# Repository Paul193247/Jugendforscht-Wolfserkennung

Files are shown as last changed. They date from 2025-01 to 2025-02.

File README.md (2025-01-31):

# Jugend forscht: Wolfserkennung

## 1. Idee
Ich war schon immer ein Tierfreund, und als ich wiederholt Artikel im *Stader Tageblatt* gelesen habe, dass Wölfe, die Weidetiere wie Schafe oder Rinder reißen, zum Abschuss freigegeben werden, entstand die Idee zu meinem Projekt. Eine Zusammenarbeit mit der Wolfsberaterin Svenja Oßenbrügge ergab, dass ein KI-unterstütztes Kamerasystem sehr wichtig für das Wolfsmonitoring wäre, da die Hälfte der Wolfsrisse mutmaßlich auf Hunde zurückzuführen sind. Eindeutige Bilder sorgen für Aufklärung, und mein entwickeltes Alarmsystem kann Tiere schützen.

## 2. Ziel
- Das neuronale Netzwerk aus dem Vorjahr verbessern und so anpassen, dass es sowohl Hunde als auch Wölfe erkennen kann.
- Das neuronale Netzwerk mit dem Raspberry Pi verbinden.
- Die Kamera aus dem Vorjahr verbessern.
- Eine Möglichkeit einbauen, dass der Raspberry Pi unabhängig von WLAN-Netzwerken eine SMS senden kann.
- Alles in einer funktionalen Kamerabox verbinden, die bei einer Bewegung ein Video aufnimmt, dieses klassifiziert und gegebenenfalls eine SMS-Nachricht an den Verantwortlichen sendet.

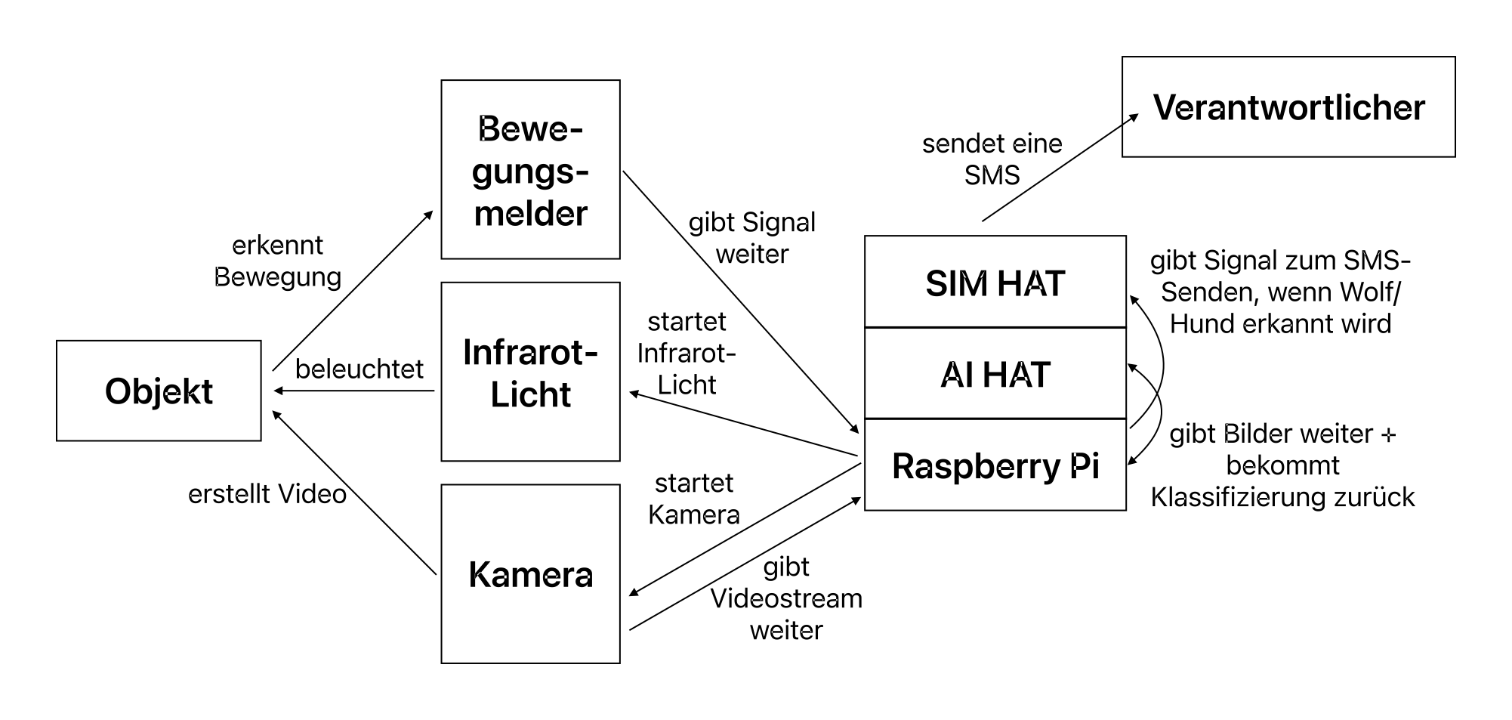
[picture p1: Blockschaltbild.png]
Blockschaltbild


## 3. Vorgehensweise
### 3.1 Wie bin ich vorgegangen?
- Trainingsdaten mit Roboflow vorbereitet.
- Mit YOLOv8 ein Modell erstellt.
- Modell auf Google Colab trainiert.
- Modell in das `.hef`-Format konvertiert.
- Python-Programm geschrieben, das auf dem Raspberry Pi läuft und bei einer Bewegung den Kamera-Stream mit der Klassifizierung öffnet.

### 3.2 Problemlösemethoden bei der KI-Entwicklung
Problem aufgetreten → Hypothese aufstellen → Versuch entwickeln → erneut testen → ggf. einsatzbereit machen oder weitere Lösungen entwickeln.

### 3.3 Verwendete Hardware
#### 3.3.1 Raspberry Pi
Der Raspberry Pi ist ein Minicomputer. Auf diesem läuft das Python-Programm, welches sozusagen alles koordiniert.

#### 3.3.2 Raspberry Pi Kamera v3
Ich verwende die Raspberry Pi Kamera v3, die im Gegensatz zu meiner vorherigen Kamera einen Autofokus hat und keinen Infrarotfilter besitzt. Dadurch kann ich einen Infrarot-Scheinwerfer verwenden.

#### 3.3.3 SIM-HAT
Zur SMS-Benachrichtigung setze ich das Waveshare SIM7600E-H 4G HAT ein, womit der Raspberry Pi unabhängig von WLAN-Netzwerken SMS versenden kann.

#### 3.3.4 Infrarot-LED
Um auch nachts Aufnahmen zu ermöglichen, nutze ich eine Infrarot-LED, die für meine Kamera sichtbar ist, aber andere Tiere nicht stört.

#### 3.3.5 AI-HAT
Mein vorheriges System benötigte ca. 20-30 Sekunden zur Bildverarbeitung. Mit dem Raspberry Pi AI HAT (13 TOPS) kann ich einen 30fps-Videostream live verarbeiten. Dadurch wird das System echtzeitfähig, was eine schnellere Alarmierung ermöglicht.

## 4. Tests
### 4.1 Vorversuch mit meiner Katze
Viele Funktionalitäten meines Systems wurden an meiner Katze entwickelt und getestet.

### 4.2 Hund
Da ich keinen eigenen Hund habe, testete ich die KI mit Hunden von Freunden und Bekannten – sowohl mit einem Videostream als auch mit einzelnen Bildern. Die Erkennungsrate war hoch; wenn ein Hund nicht erkannt wurde, lag es meist daran, dass er weit hinten im Bild war.

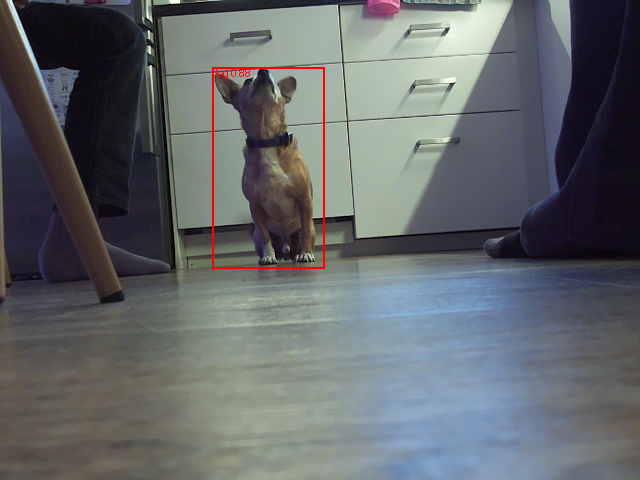
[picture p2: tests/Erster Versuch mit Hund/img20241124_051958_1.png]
Versuch mit Hund

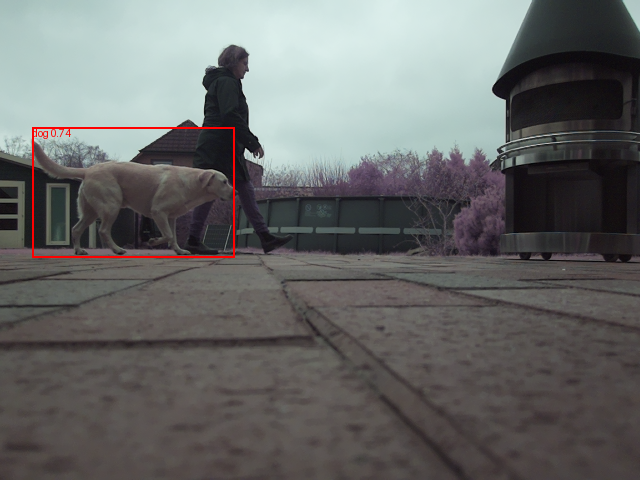
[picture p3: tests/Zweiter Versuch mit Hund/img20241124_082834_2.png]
Versuch mit Hund


### 4.3 Wolf
Um die KI an echten Wölfen zu testen, besuchte ich den Wildpark Schwarze Berge. Dort unterstützte mich die Wolfsberaterin Svenja Oßenbrügge beim Anlocken der Wölfe. Die Genauigkeit meiner KI war sehr zufriedenstellend. Eine Schwäche zeigte sich bei liegenden Wölfen, da es hiervon nur wenige Trainingsbilder gab.

Versuch mit Wolf

## 5. Was ist neu?
- Raspberry Pi
- AI-HAT
- SIM-HAT
- Raspberry Pi Kamera
- Neuronales Netzwerk
- Infrarot-LED
- Python-Programm
- 3D-gedruckte Box

## 6. Zielerreichung
- Ich habe das neuronale Netzwerk mit YOLOv8 verbessert.
- Die KI kann nun Hunde und Wölfe erkennen, was entscheidend für das Wolfsmonitoring ist.
- Meine Kamera hat jetzt Autofokus.
- Der Raspberry Pi kann nun SMS-Nachrichten verschicken.
- Alle Komponenten sind in einer funktionalen Kamerabox integriert.

## 7. Ergebnisdiskussion
Mein Kamerasystem soll Tierhalter wie Schafhirten vor angreifenden Hunden oder Wölfen warnen, damit sie rechtzeitig reagieren und ihre Tiere schützen können. Außerdem soll es Wolfsberatern bei Wildrissen helfen, zwischen Hund und Wolf zu unterscheiden und wichtige Erkenntnisse über das Verhalten von Wölfen liefern. Derzeit fehlen oft Bild- oder Videobeweise bei Wolfsrissen, sodass Entscheidungen nur auf DNA-Proben und Angriffsweisen basieren. Videoaufnahmen könnten Fehleinschätzungen minimieren und das Wolfsmonitoring verbessern. 

Alle Systemkomponenten wurden erfolgreich getestet: Der Bewegungsmelder funktionierte mit meiner Katze, und die KI erkannte zuverlässig Hunde und Wölfe – dies konnte ich mit echten Tieren bestätigen. Mein System ist nun echtzeitfähig, wetterfest, tag- und nachttauglich sowie internetfähig. 

In Zukunft könnte eine Zusammenarbeit mit kompetenten Partnern wie Schäfern, Jägern, Wolfsberatern, Verhaltensforschern, Rangern oder Wildhütern angestrebt werden.

## 8. Danksagung
Ich möchte mich herzlich bei all jenen bedanken, die mich bei meinem Projekt unterstützt und motiviert haben:
- **Privatdozent Dr. Carmesin**, der mein Projekt betreut und mir bei der Organisation geholfen hat.
- **Frau von Bargen**, die mir mit viel Geduld, Interesse und Hilfsbereitschaft insbesondere beim Schreiben der Langfassung zur Seite stand.
- **Svenja Oßenbrügge**, Wolfsberaterin des Landkreises Hamburg-Harburg, sowie dem *Wildpark Schwarze Berge* für wertvolle Informationen und Unterstützung bei der Wolfsbeobachtung.
- **Jannes Ruder** für das 3D-Modelling und Drucken meiner Box.
- **Florian von Bargen und meiner Familie**, die stets ein offenes Ohr für mich hatten.

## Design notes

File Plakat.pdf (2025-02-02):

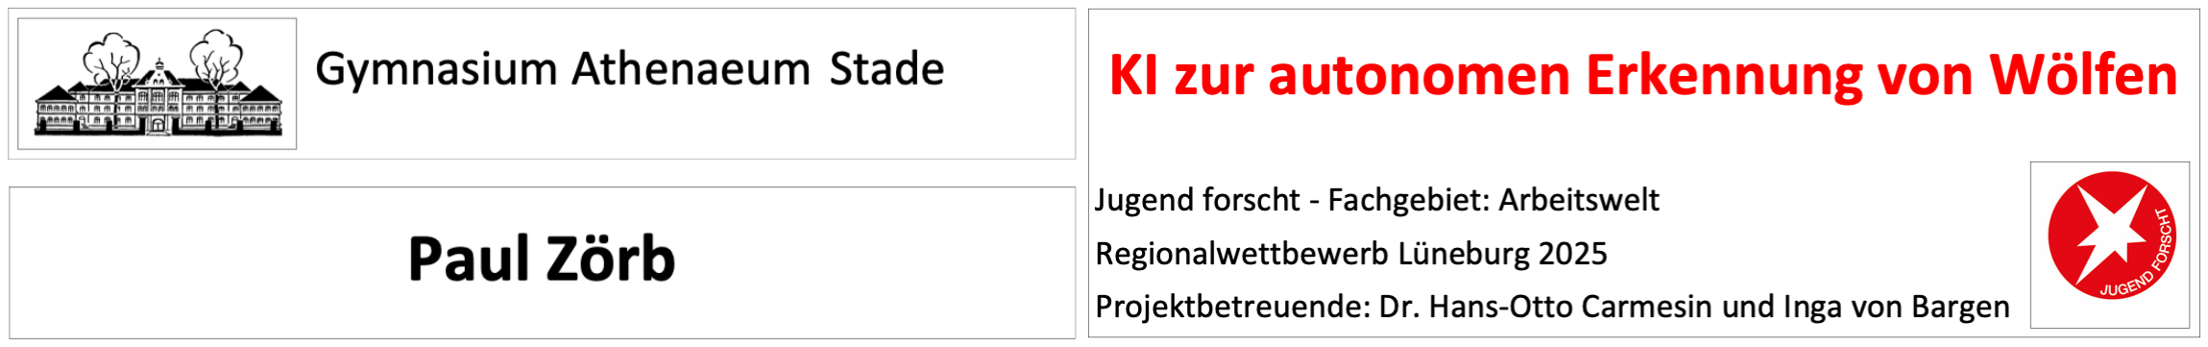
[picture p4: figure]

# 1. Idee

Ich war schon immer ein Tierfreund und als ich wiederholt Artikel im Stader Tageblatt gelesen habe, dass Wölfe, die Weidetiere wie Schafe oder Rinder reißen, zum Abschuss freigegeben werden, entstand die Idee zu meinem Projekt. Eine Zusammenarbeit mit der Wolfsberaterin Svenja Oßenbrügge bestätigte, dass ein KI unterstütztes Kamerasystem sehr wichtig für das Wolfsmonitoring wäre, da die Hälfte der Wolfsrisse mutmaßlich auf Hunde zurückzuführen sind. Eindeutige Bilder sorgen für Aufklärung und mein entwickeltes Alarmsystem kann Tiere schützen.

# 2. Ziel

- Das neuronale Netzwerk aus dem Vorjahr verbessern und so anpassen, dass es sowohl Hunde als auch Wölfe erkennen kann
- Das neuronale Netzwerk mit dem Raspberry Pi verbinden
- Die Kamera aus dem Vorjahr verbessern
- Eine Möglichkeit einbauen, dass der Raspberry Pi unabhängig von WLAN-Netzwerken eine SMS senden kann
- Alles in einer funktionalen Kamerabox verbinden, die, wenn sie eine Bewegung erkennt, ein Video aufnimmt, dieses klassifiziert und zuletzt gegebenenfalls eine SMS-Nachricht an den Verantwortlichen sendet

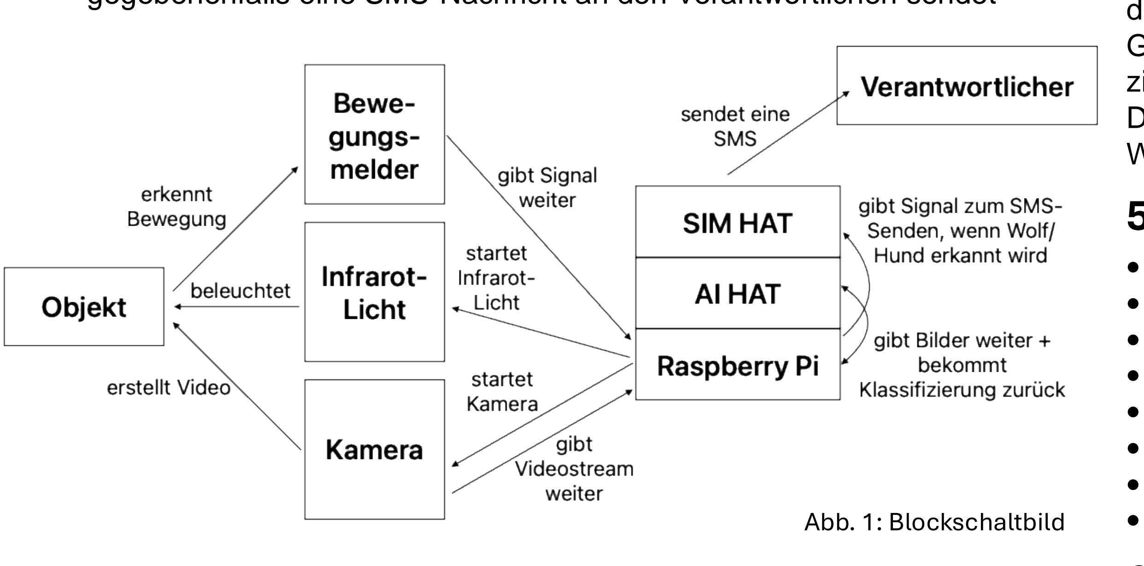
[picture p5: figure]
Abb. 1: Blockschaltbild

# 3. Vorgehensweise

## 3.1 Wie bin ich vorgegangen?

- Trainingsdaten mit Roboflow vorbereitet
- Mit YOLOv8 ein Modell erstellt
- Modell auf Google Colab trainiert
- Modell in das .hef-Format konvertiert
- Python Programm geschrieben, welches auf dem Raspberry Pi läuft und bei einer Bewegung den Kamera-Stream mit der Klassifizierung öffnet

## 3.2 Problemlösemethoden bei der KI-Entwicklung

Problem aufgetreten → Hypothese aufstellen → Versuch entwickeln → erneut testen → ggf. einsatzbereit machen oder weitere Lösungen entwickeln

## 3.3 Verwendete Hardware

### 3.3.1 Raspberry Pi 5

Der Raspberry Pi 5 ist ein Minicomputer. Auf diesem läuft das Python-Programm, welches sozusagen alles koordiniert.

### 3.3.2 Raspberry Pi Kamera v3

Um die Bilder, bzw. Videos aufzunehmen, verwende ich die Raspberry Pi Kamera v3. Diese hat im Gegensatz zu meiner vorherigen Kamera einen Autofokus und hat keinen Infrarotfilter, sodass ich einen Infrarot-Scheinwerfer verwenden kann.

### 3.3.3 SIM-Hat

Um eine SMS an den Verantwortlichen zu senden, verwende ich den Waveshare SIM7600E-H 4g HAT. Mit diesem kann ich unabhängig von WLAN-Netzwerken SMS-Nachrichten versenden.

### 3.3.4 Infrarot-LED

Damit meine Kamera auch in der Nacht sehen kann, verwende ich eine Infrarot-LED, da meine Kamera keinen Infrarot Filter hat und somit keine anderen Tiere durch das Licht gestört werden.

### 3.3.5 AI-HAT

Da mein vorheriges System ca. 20-30 Sekunden brauchte, um ein Bild zu verarbeiten, verwende ich den Raspberry Pi AI HAT. Dieser hat 13 TOPS und ich kann mit ihm einen 30fps Videostream meiner Kamera live verarbeiten, womit mein System nun echtzeitfähig ist. Dieses hat den Vorteil, dass durch die höhere Verarbeitungsgeschwindigkeit mehr Frames analysiert und erkannt werden können. Dieses sichert und erhöht die Qualität der Wolfserkennung und führt schneller zu einem Alarm, da ein Verarbeitungsrückstau an einzeln aufgenommen Fotos vermieden wird.

## 4. Tests

## 4.1 Vorversuch mit meiner Katze

Am Beispiel meiner Katze wurden viele Funktionalitäten meines Systems entwickelt und getestet.

## 4.2 Hund

Um zu erkennen, ob die Kamera relevante Tiere erkennt, habe ich dies zunächst an Hunden ausprobiert. Da ich selbst keinen Hund habe, testete ich dies an Hunden von Freunden, bzw. Bekannten. Dies habe ich sowohl mit einem Videostream als auch mit einzelnen Bildern gemacht. Die Hunde wurden fast immer erkannt. Wenn sie nicht erkannt wurden, lag dies meist daran, dass sich der Hund sehr weit hinten im Bild befand.

## 4.3 Wolf

Um auszuprobieren, ob meine KI auch mit echten Wölfen funktioniert und nicht nur mit Hunden, bin ich in den Wildpark Schwarze Berge gefahren, um dort meine Kamera an den Wölfen auszuprobieren. Vor Ort hat mir die Wolfsberaterin Svenja Oßenbrügge geholfen, indem sie die Wölfe angelockt hat, da das Gehege sehr groß ist. Die Genauigkeit meiner KI bei diesem Versuch war sehr zufriedenstellend. Die Wölfe wurden im Gegensatz zum letzten Wildparkbesuch fast immer erkannt. Die so ziemlich einzige Ausnahme war, wenn der Wolf flach auf dem Boden lag. Dies liegt höchstwahrscheinlich daran, dass es wenig Bilder von liegenden Wölfen im meinen Trainingsbildern gab.

# 5. Was ist neu?

- Raspberry Pi
- AI HAT
- SIM-HAT
- Raspberry Pi Kamera
- Neuronales Netzwerk
- Infrarot LED
- Python-Programm
- 3D-Gedrucke Box

# 6. Zielerreichung

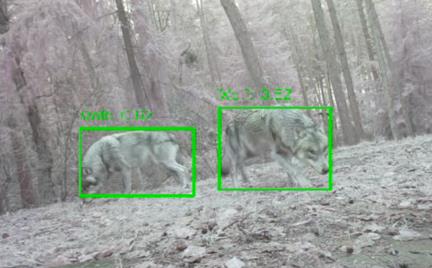
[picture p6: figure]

- Ich habe das neuronale Netzwerk mit YOLOv8 verbessert
- Das neuronale Netzwerk kann nun Hunde und Wölfe erkennen, was entscheidend für die Verbesserung des Wolfsmonitorings ist
- Ich habe nun eine Kamera mit Autofokus
- Mein Raspberry Pi hat nun einen SIM-HAT und somit die Möglichkeit SMS-Nachrichten an einen Verantwortlichen zu verschicken
- Ich habe alles in einer funktionalen Kamerabox verbunden

# 7. Ergebnisdiskussion

Mein Kamerasystem soll Tierhalter wie Schafhirten vor angreifenden Hunden oder Wölfen warnen, damit sie rechtzeitig reagieren und ihre Tiere schützen können. Außerdem soll es Wolfberatern, bei Wildrissen helfen zwischen Hund und Wolf zu unterscheiden und wichtige Erkenntnisse über das Verhalten von Wölfen liefern. Derzeit fehlen oft Bild- oder Videobeweise bei Wolfsrissen, sodass Entscheidungen nur auf DNA-Proben und Angriffsweisen basieren. Videoaufnahmen könnten Fehleinschätzungen minimieren und das Wolfsmonitoring verbessern. Ich habe alle Systemkomponenten erfolgreich getestet: Der Bewegungsmelder funktionierte mit meiner Katze, und die KI erkannte zuverlässig Hunde und Wölfe, was ich erfolgreich mit echten Tieren bestätigen konnte. Mein System ist nun echtzeitfähig und einsatzbereit, Tag und Nacht tauglich, wetterfest und internetfähig. Dadurch sollten in Zukunft eine Zusammenarbeit mit kompetenten Partnern angestrebt werden, zum Beispiel Schäfer, Jäger, Wolfsberater, Verhaltensforscher, Ranger, Wildhüter.

# 8. Danksagung

An dieser Stelle möchte ich mich bei all denjenigen bedanken, die mich bei meinem Projekt unterstützt und motiviert haben. Zuerst gebührt mein Dank Herrn Privatdozent Dr. Carmesin, der mein Projekt betreut und mir bei der Organisation des Projektes geholfen hat. Ein besonderer Dank gilt Frau von Bargen, die mir mit viel Geduld, Interesse und Hilfsbereitschaft insbesondere beim Schreiben der Langfassung zur Seite stand. Ich möchte mich außerdem bei Svenja Oßenbrügge, Wolfsberaterin Landkreis Hamburg-Harburg, und dem Wildpark Schwarze Berge für die vertiefenden, weiterführenden Informationen zum Riss von Weide- und Nutztieren und für die Unterstützung bei der Wolfsbeobachtung am Wolfsgehege des Wildparks Schwarze Berge bedanken. Ich möchte mich außerdem bei Jannes Ruder für das 3D-Modelling und Drucken meiner Box bedanken. Zu guter Letzt möchte ich mich bei Florian von Bargen und meiner Familie bedanken, die stets ein offenes Ohr für mich hatten.

Abb. 2

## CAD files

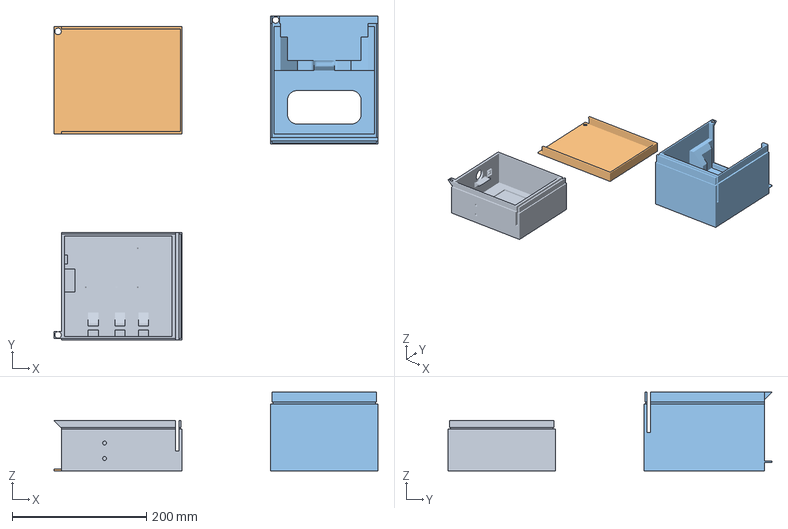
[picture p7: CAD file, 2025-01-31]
Box 3d/jufo Box v3.3mf
482.7 x 482.7 x 117.4 mm
jufo paul v0 v10.stl_A
jufo paul v0 v10.stl_B_B
jufo paul v0 v10.stl_B_A

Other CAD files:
Box 3d/jufo box v13.f3d

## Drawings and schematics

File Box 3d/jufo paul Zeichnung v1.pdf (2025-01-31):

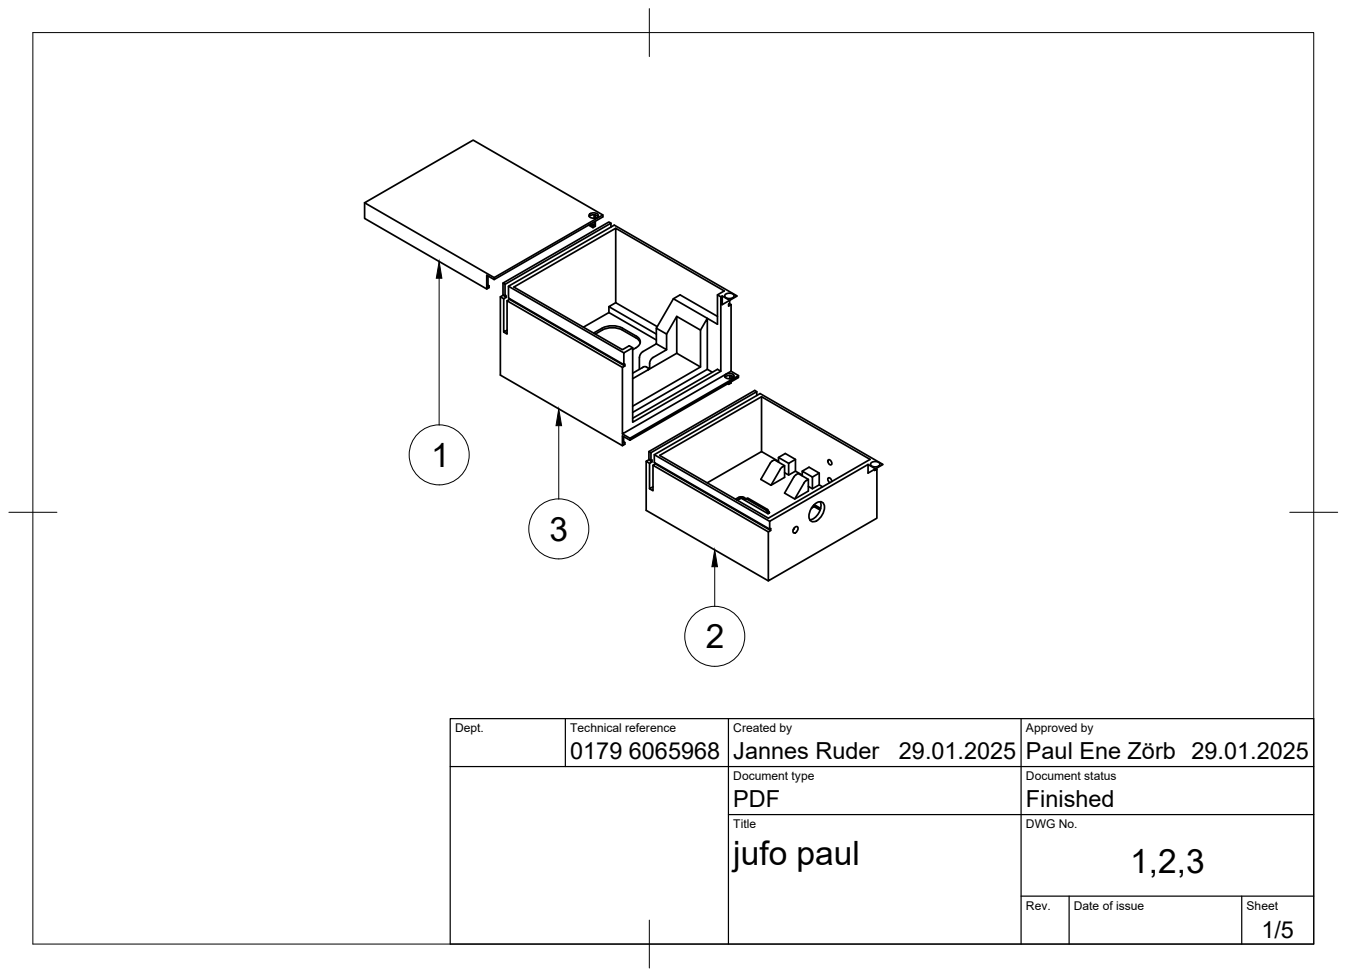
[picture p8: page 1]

Dept. | Technical reference 0179 6065968 | Created by Jannes Ruder 29.01.2025 | Approved by Paul Ene Zörb 29.01.2025

Document type PDF | Document status Finished

Title jufo paul | DWG No. 1,2,3

Rev. | Date of issue | Sheet

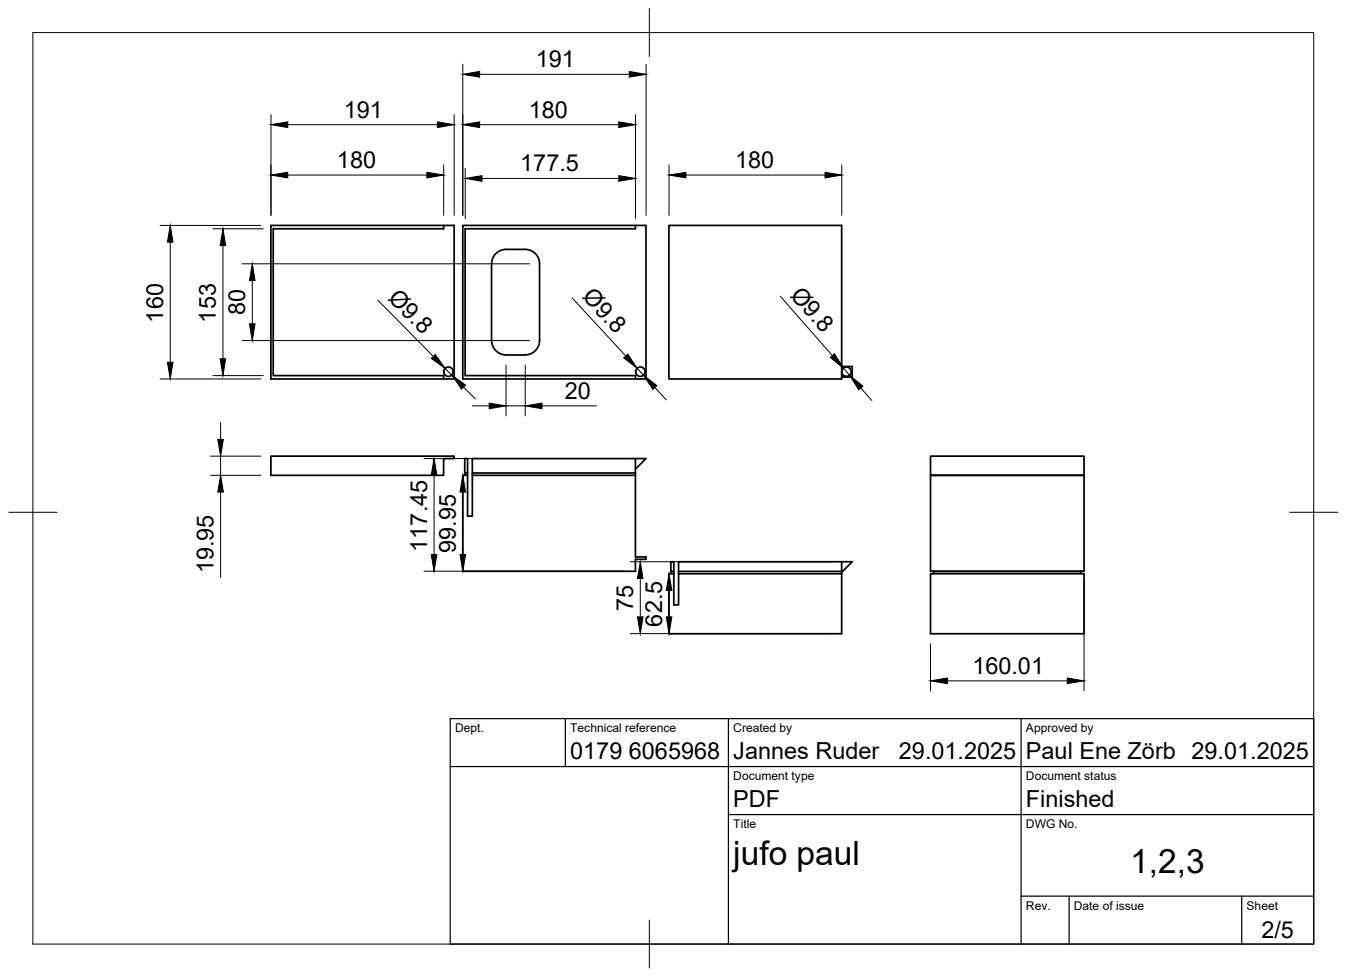
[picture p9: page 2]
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

Document type PDF | Document status Finished

Title jufo paul | DWG No. 1,2,3

Rev. | Date of issue | Sheet

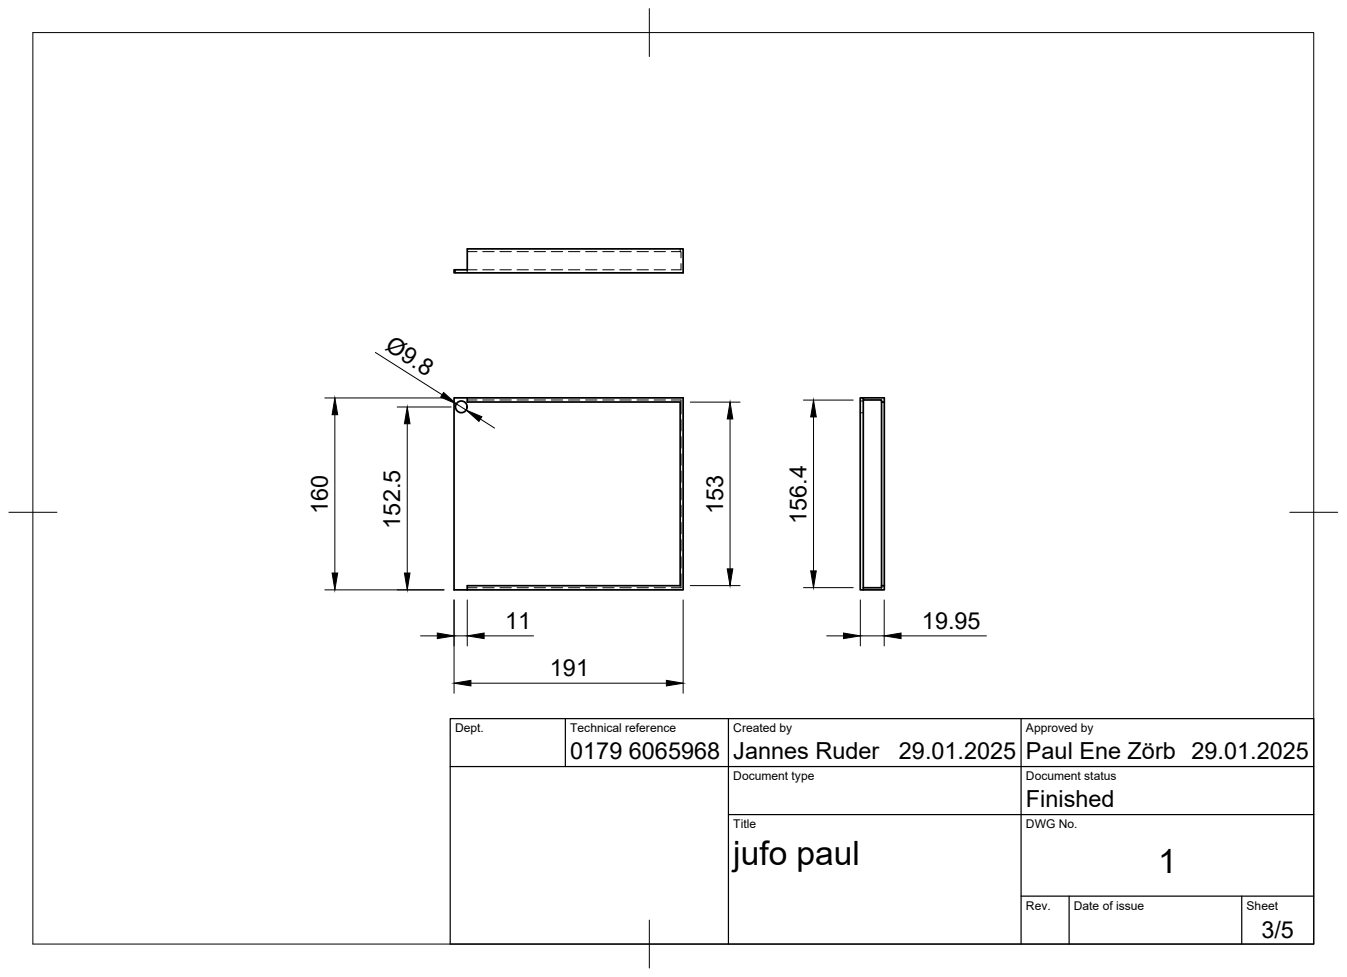
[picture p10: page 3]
Jannes Ruder; Paul Ene Zörb 160

Dept. | Technical reference | Created by 29.01.2025 | Approved by 29.01.2025

Document type | Document status Finished

Title jufo paul | DWG No. 1

Rev. | Date of issue | Sheet

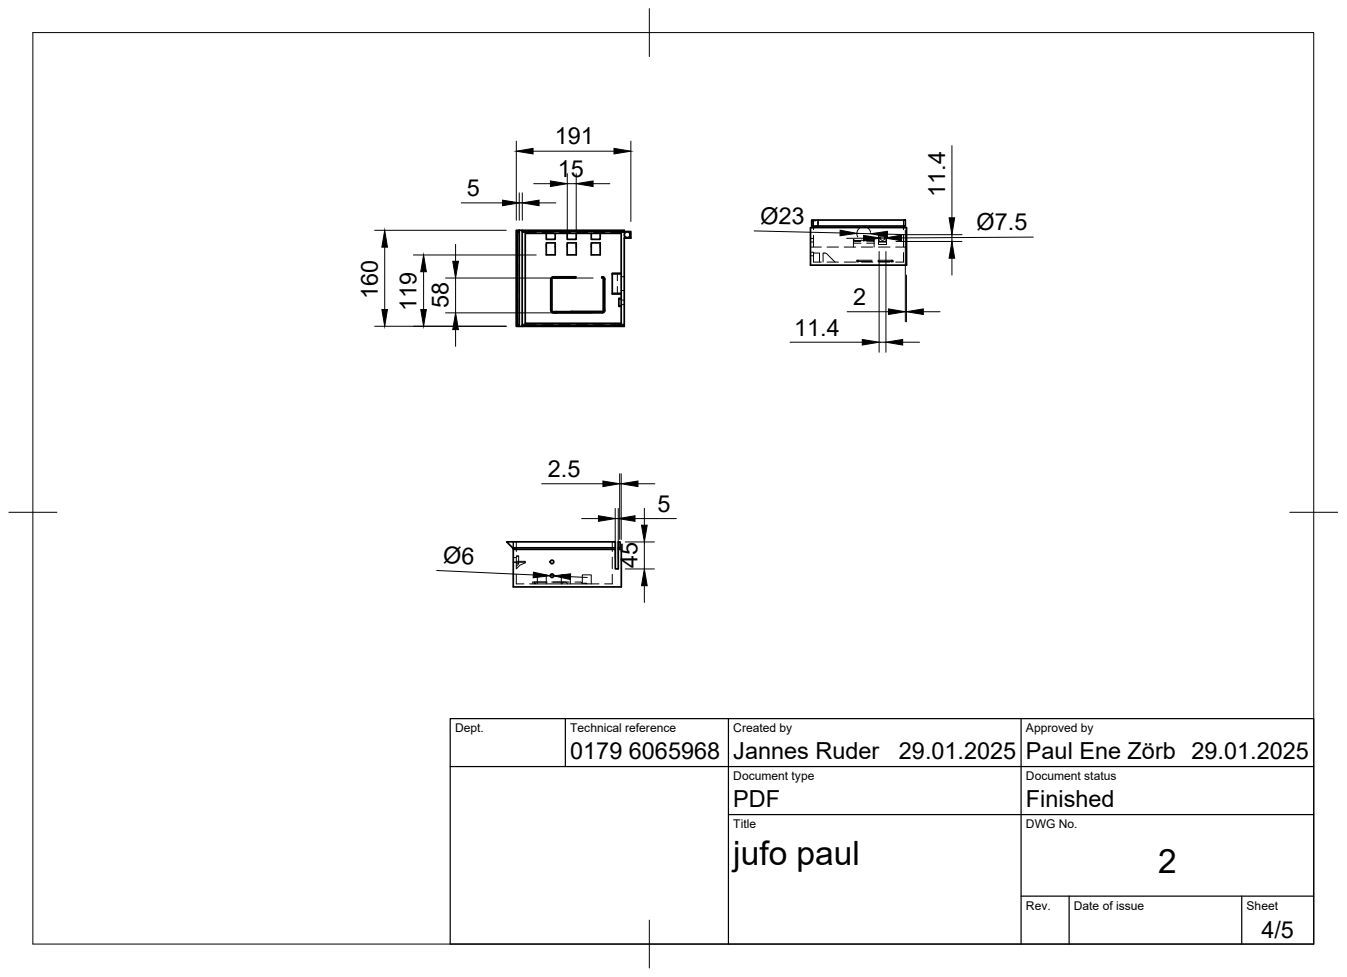
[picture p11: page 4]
Jannes Ruder; Paul Ene Zörb 160

Dept. | Technical reference | Created by 29.01.2025 | Approved by 29.01.2025

Document type PDF | Document status Finished

Title jufo paul | DWG No. 2

Rev. | Date of issue | Sheet

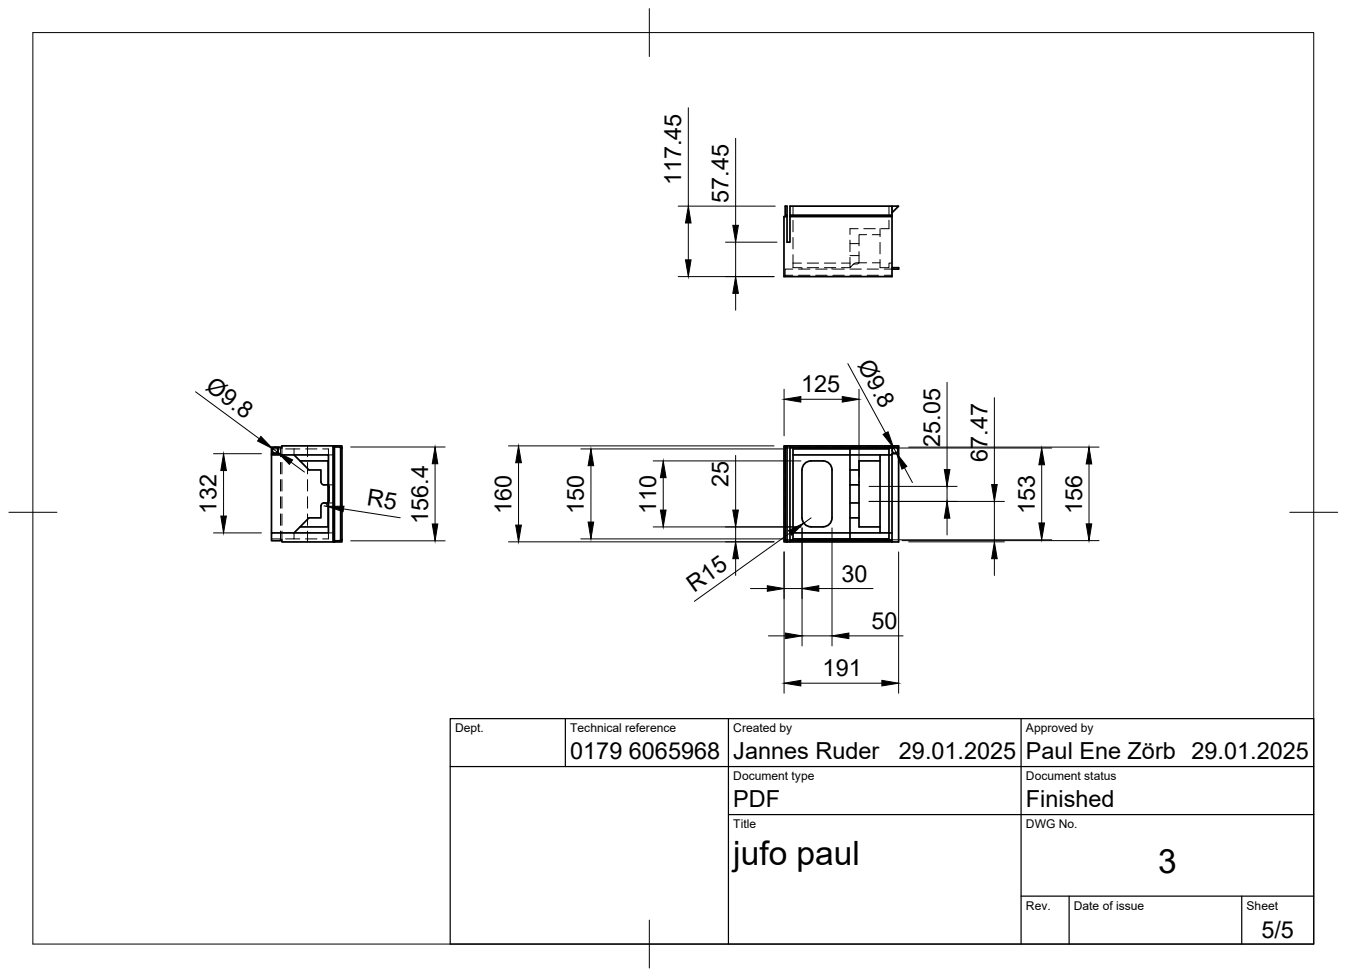
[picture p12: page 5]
Jannes Ruder; Paul Ene Zörb 160

Dept. | Technical reference | Created by 29.01.2025 | Approved by 29.01.2025

Document type PDF | Document status Finished

Title jufo paul | DWG No. 3

Rev. | Date of issue | Sheet

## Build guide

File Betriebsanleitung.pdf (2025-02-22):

## 1. Stromversorgung

Der Raspberry Pi verbraucht im Ruhezustand etwa 6,5 W. Sobald eine Bewegung erkannt und ein Video aufgenommen wird, steigt der Verbrauch auf 21,5 W.

Während einer zweitägigen Laufzeit im Wildpark Schwarze Berge wurden insgesamt 1,5 Stunden Video aufgenommen, was 5% der Zeit entspricht. Daraus ergibt sich ein durchschnittlicher Energieverbrauch von 7,25 W.

## Empfehlung zur Stromversorgung:

- Netzstrom ist die beste Option, sofern verfügbar.
- Falls kein Netzanschluss vorhanden ist, sollte die Box über eine Powerstation mit Steckdose betrieben werden.
- Eine herkömmliche Powerbank ist ungeeignet, da die verschiedenen Systeme der Box unterschiedliche Spannungen und Stromstärken benötigen. Diese werden über spezielle Netzgeräte reguliert, die Netzstrom erfordern. Zudem haben Powerbanks meist nicht genügend Wattstunden, um die Box über längere Zeit zu versorgen.

## Berechnung der Laufzeit mit einer Powerstation:

- Eine 100-Wh-Powerstation reicht für ca. 13,79 Stunden.
- Um eine tägliche Versorgung mit nur einem Wechsel zu gewährleisten, sollte die Powerstation mindestens 200 Wh haben.

## 2. Eigene KI erstellen

Hier eine Schritt-für-Schritt-Anleitung, um ein eigenes KI-Modell mit YOLOv8 und Roboflow zu trainieren:

## 1. Roboflow-Account erstellen

Zunächst unter app.roboflow.com einen Account anlegen.

## 2. Neues Projekt in Roboflow erstellen

- Im Projects-Tab auf „New Project“ klicken.
- Object Detection als Typ wählen.
- Einen passenden Projektnamen und eine Annotation Group festlegen.

## 3. Bilder hochladen

- Unter „Upload Data“ die gewünschten Bilder hochladen.
- Anschließend auf „Save and Continue“ klicken.

## 4. Bilder labeln

- Die Bilder können manuell, automatisch oder durch Labeling-Dienste annotiert werden.
- Danach das gelabelte Dataset speichern.

## 5. Version erstellen und Modell exportieren

- Unter dem Versions-Tab eine neue Version des Datasets erstellen.
- Danach kann das Modell für YOLOv8 exportiert werden.

## 6. Dataset auf Google Drive speichern & in Google Colab hochladen

- Das Dataset auf Google Drive hochladen und mit Google Colab verbinden.
- Alternativ kann es direkt ins Google Colab Notebook hochgeladen werden.

## 7. Trainings-Skript herunterladen und in Google Colab öffnen

- Das Skript train_model.ipynb von GitHub (https://github.com/Paul193247/Jugendforscht-Wolfserkennung) herunterladen.
- Die Datei auf Google Drive speichern und in Google Colab öffnen.

## 8. Pfad zur .yaml-Datei im Skript anpassen

- In der letzten Zelle, in der train aufgerufen wird, den ersten String nach model durch den Pfad zur .yaml-Datei im Dataset ersetzen.

## 9. Alle Zellen ausführen & Modell trainieren

- Alle Zellen im Notebook ausführen.
- Das Modell wird nun trainiert und ist einsatzbereit!

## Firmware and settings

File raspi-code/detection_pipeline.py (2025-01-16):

import gi
gi.require_version('Gst', '1.0')
from gi.repository import Gst, GLib
import os
import argparse
import multiprocessing
import numpy as np
import setproctitle
import cv2
import time
import hailo
from hailo_rpi_common import (
    get_default_parser,
    QUEUE,
    SOURCE_PIPELINE,
    INFERENCE_PIPELINE,
    INFERENCE_PIPELINE_WRAPPER,
    USER_CALLBACK_PIPELINE,
    DISPLAY_PIPELINE,
    GStreamerApp,
    app_callback_class,
    dummy_callback,
    detect_hailo_arch,
)



# -----------------------------------------------------------------------------------------------
# User Gstreamer Application
# -----------------------------------------------------------------------------------------------

# This class inherits from the hailo_rpi_common.GStreamerApp class
class GStreamerDetectionApp(GStreamerApp):
    def __init__(self, app_callback, user_data, output):
        parser = get_default_parser()
        parser.add_argument(
            "--labels-json",
            default="/home/paul/Wolferkennung/hailo-rpi5-examples/resources/cytron-labels.json",
            help="Path to costume labels JSON file",
        )
        self.output = output
        args = parser.parse_args()
        # Call the parent class constructor
        super().__init__(args, user_data)
        # Additional initialization code can be added here
        # Set Hailo parameters these parameters should be set based on the model used
        self.batch_size = 2
        self.network_width = 640
        self.network_height = 640
        self.network_format = "RGB"
        nms_score_threshold = 0.3
        nms_iou_threshold = 0.45


        # Determine the architecture if not specified
        if args.arch is None:
            detected_arch = detect_hailo_arch()
            if detected_arch is None:
                raise ValueError("Could not auto-detect Hailo architecture. Please specify --arch manually.")
            self.arch = detected_arch
            #print(f"Auto-detected Hailo architecture: {self.arch}")
        else:
            self.arch = args.arch


        if args.hef_path is not None:
            self.hef_path = args.hef_path
        # Set the HEF file path based on the arch
        elif self.arch == "hailo8":
            self.hef_path = os.path.join(self.current_path, '../resources/yolov8m.hef')
        else:  # hailo8l
            self.hef_path = os.path.join(self.current_path, '../resources/yolov8s_h8l.hef')

        # Set the post-processing shared object file
        self.post_process_so = os.path.join(self.current_path, '../resources/libyolo_hailortpp_postprocess.so')

        # User-defined label JSON file
        self.labels_json = args.labels_json
        #print(self.labels_json)

        self.app_callback = app_callback

        self.thresholds_str = (
            f"nms-score-threshold={nms_score_threshold} "
            f"nms-iou-threshold={nms_iou_threshold} "
            f"output-format-type=HAILO_FORMAT_TYPE_FLOAT32"
        )

        # Set the process title
        setproctitle.setproctitle("Hailo Detection App")

        self.create_pipeline()

    def get_pipeline_string(self):
        source_pipeline = SOURCE_PIPELINE(self.video_source)
        detection_pipeline = INFERENCE_PIPELINE(
            hef_path=self.hef_path,
            post_process_so=self.post_process_so,
            batch_size=self.batch_size,
            config_json=self.labels_json,
            additional_params=self.thresholds_str)
        user_callback_pipeline = USER_CALLBACK_PIPELINE()
        display_pipeline = DISPLAY_PIPELINE(video_sink=self.video_sink, sync=self.sync, show_fps=self.show_fps)
        pipeline_string = (
            f'{source_pipeline} '
            f'{detection_pipeline} ! '
            f'{user_callback_pipeline} ! '
            f'{display_pipeline}'
        )
        if not self.output:
            pipeline_string = """libcamerasrc name=source ! video/x-raw, format=RGB, width=1536, height=864 !  queue name=source_scale_q leaky=no max-size-buffers=3 max-size-bytes=0 max-size-time=0  ! videoscale name=source_videoscale n-threads=2 ! queue name=source_convert_q leaky=no max-size-buffers=3 max-size-bytes=0 max-size-time=0  ! videoconvert n-threads=3 name=source_convert qos=false ! video/x-raw, format=RGB, pixel-aspect-ratio=1/1 !  queue name=inference_scale_q leaky=no max-size-buffers=3 max-size-bytes=0 max-size-time=0  ! videoscale name=inference_videoscale n-threads=2 qos=false ! queue name=inference_convert_q leaky=no max-size-buffers=3 max-size-bytes=0 max-size-time=0  ! video/x-raw, pixel-aspect-ratio=1/1 ! videoconvert name=inference_videoconvert n-threads=2 ! queue name=inference_hailonet_q leaky=no max-size-buffers=3 max-size-bytes=0 max-size-time=0  ! hailonet name=inference_hailonet hef-path=/home/paul/Wolferkennung/hailo-rpi5-examples/basic_pipelines/../resources/yolov8m.hef batch-size=2 nms-score-threshold=0.3 nms-iou-threshold=0.45 output-format-type=HAILO_FORMAT_TYPE_FLOAT32 force-writable=true ! queue name=inference_hailofilter_q leaky=no max-size-buffers=3 max-size-bytes=0 max-size-time=0  ! hailofilter name=inference_hailofilter so-path=/home/paul/Wolferkennung/hailo-rpi5-examples/basic_pipelines/../resources/libyolo_hailortpp_postprocess.so  config-path=/home/paul/Wolferkennung/hailo-rpi5-examples/resources/cytron-labels.json   qos=false  ! queue name=identity_callback_q leaky=no max-size-buffers=3 max-size-bytes=0 max-size-time=0  ! identity name=identity_callback  ! queue name=hailo_display_hailooverlay_q leaky=no max-size-buffers=3 max-size-bytes=0 max-size-time=0  ! hailooverlay name=hailo_display_hailooverlay ! queue name=hailo_display_videoconvert_q leaky=no max-size-buffers=3 max-size-bytes=0 max-size-time=0  ! videoconvert name=hailo_display_videoconvert n-threads=2 qos=false ! queue name=hailo_display_q leaky=no max-size-buffers=3 max-size-bytes=0 max-size-time=0  ! fpsdisplaysink name=hailo_display video-sink=fakesink sync=false text-overlay=false signal-fps-measurements=false"""
        return pipeline_string

if __name__ == "__main__":
    # Create an instance of the user app callback class
    user_data = app_callback_class()
    app_callback = dummy_callback
    app = GStreamerDetectionApp(app_callback, user_data)
    app.run()

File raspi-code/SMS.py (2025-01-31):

import threading
import RPi.GPIO as GPIO
import serial
import time

# Definiere das Lock
serial_lock = threading.Lock()

ser = serial.Serial("/dev/ttyAMA0", 115200)
ser.flushInput()

phone_number = '015733666642'  # Die Telefonnummer zum Senden der SMS
text_message = 'test'
power_key = 6

def send_at(command, back, timeout):
    print("command", command)
    rec_buff = ''
    ser.write((command+'\r\n').encode())
    time.sleep(timeout)
    if ser.inWaiting():
        time.sleep(0.01)
        rec_buff = ser.read(ser.inWaiting()).decode('utf-8')
    print("rec_buff", rec_buff)
    if back not in rec_buff:
        print(command + ' ERROR')
        print(command + ' back:\t' + rec_buff)
        return 0
    else:
        return 1

def SendShortMessage(phone_number, text_message):
    power_on(power_key)
    print("Setting SMS mode...")
    send_at("AT+CMGF=1", "OK", 1)
    print("Sending Short Message")
    answer = send_at("AT+CMGS=\""+phone_number+"\"", ">", 2)
    if 1 == answer:
        ser.write(text_message.encode())
        ser.write(b'\x1A')
        answer = send_at('', "OK", 20)
        if 1 == answer:
            print('send successfully')
        else:
            print('error')
    else:
        print('error%d' % answer)
    power_down(power_key)

def power_on(power_key):
    print('SIM7600X is starting:')
    GPIO.setmode(GPIO.BCM)
    GPIO.setwarnings(False)
    GPIO.setup(power_key, GPIO.OUT)
    time.sleep(0.1)
    GPIO.output(power_key, GPIO.HIGH)
    time.sleep(2)
    GPIO.output(power_key, GPIO.LOW)
    time.sleep(20)
    ser.flushInput()
    print('SIM7600X is ready')

def power_down(power_key):
    print('SIM7600X is logging off:')
    GPIO.output(power_key, GPIO.HIGH)
    time.sleep(3)
    GPIO.output(power_key, GPIO.LOW)
    time.sleep(18)
    print('Good bye')

# Thread-safe SMS senden
def send_message_thread(animal):
    with serial_lock:  # Lock wird verwendet, um den Zugriff zu synchronisieren
        SendShortMessage("015733666642", f"Ein {animal} wurde gesehen!")

# Test der Funktion im Hauptthread
if __name__ == "__main__":
    threading.Thread(target=send_message_thread, args=("Wolf",)).start()

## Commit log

2024-01-04 V2 und benachrichtigung
2025-01-16 test mit Hund und Videostream entfernt
2025-01-16 tests/Versuch\ mit\ Hund\ und\ Videostream/
2025-01-31 Add files to build your own box.
    [jufo Box v3.3mf, jufo box v13.f3d]
2025-02-16 dies und das
